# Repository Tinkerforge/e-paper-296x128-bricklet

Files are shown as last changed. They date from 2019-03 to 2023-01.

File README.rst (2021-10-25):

ePaper 128x296 Bricklet
========================

This repository contains the firmware source code and the hardware design
files. The documentation generator configs can be found at
https://github.com/Tinkerforge/generators

Repository Content
------------------

software/:
 * examples/: Examples for all supported languages
 * build/: Compiled files
 * src/: Source code of firmware
 * Makefile: Makefile to build project

hardware/:
 * Contains KiCad project files and additionally schematics as PDF

datasheets/:
 * Contains datasheets for sensors and complex ICs that are used

Hardware
--------

The hardware is designed with the open source EDA Suite KiCad
(http://www.kicad.org). Before you are able to open the files,
you have to install the Tinkerforge kicad-libraries
(https://github.com/Tinkerforge/kicad-libraries). You can either clone
them directly in hardware/ or clone them in a separate folder and
symlink them into hardware/
(ln -s kicad_path/kicad-libraries project_path/hardware). After that you
can open the .pro file in hardware/ with KiCad and from there view and
modify the schematics and the PCB layout.

Software
--------

If you want to do your own Brick/Bricklet firmware development we highly
recommend that you use our build environment setup script and read the
tutorial (https://www.tinkerforge.com/en/doc/Tutorials/Tutorial_Build_Environment/Tutorial.html).

To compile the C code we recommend you to install the newest GNU Arm Embedded
Toolchain (https://launchpad.net/gcc-arm-embedded/+download).
You also need to install bricklib2 (https://github.com/Tinkerforge/bricklib2).

You can either clone it directly in software/src/ or clone it in a
separate folder and symlink it into software/src/
(ln -s bricklib_path/bricklib2 project_path/software/src/). Finally make sure to
have CMake installed (http://www.cmake.org/cmake/resources/software.html).

After that you can build the firmware by invoking make in software/.
The firmware (.zbin) can then be found in software/build/ and uploaded
with brickv (click button "Flashing" on start screen).

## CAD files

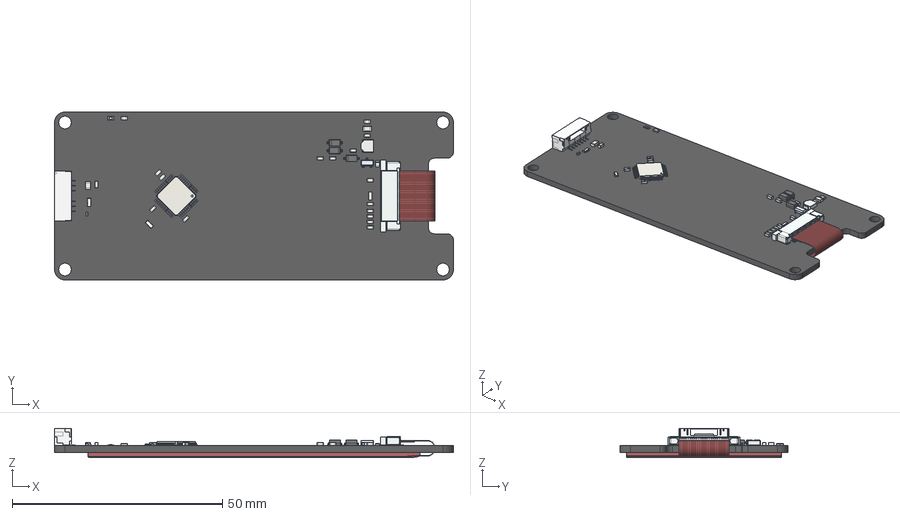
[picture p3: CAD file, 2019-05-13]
hardware/e-paper-296x128.FCStd
95.0 x 40.0 x 6.95 mm
Pcb
U2_ER-CON24HT-1_5BAE77E8
C14_C_0603_5BD03560
C1_C_0402_5BAE700F
C2_C_0603_5BAE7019
C3_C_0805_5BAE7023
C4_C_0603_5BAE702D
C5_C_0603_5BAE7037
C6_C_0603_5BAE7041
C7_C_0603_5BAE704B
C8_C_0603_5BAE7055
C9_C_0603_5BD03BE9
C10_C_0603_5BAE7069
C11_C_0603_5BAE7073
C12_C_0603_5BD0357B
C13_C_0603_5BAE7087
C15_C_0603_5BAE709B
C16_C_0603_5BAE70A5
C17_C_0603_5BAE70AF
D1_D_0603_blue_5BAE70C0
D2_SOD-123_5BAE70D4
D3_SOD-123_5BAE70E8
D4_SOD-123_5BAE70FC
L1_SPM3012_5BAE7106
P1_BrickletConn_7pin_5BAE712A
Q1_SOT23_5BAE7143
R1_R_0603_5BAE714D
R2_R_0603_5BAE7157
RP1_Cut_5BAE7167
RP2_Cut_5BAE7177
U1_lqfp48_7x7_p05_5BAE71B6
C18_C_0805_5BD07E7A
L2_R_0603_5BD075EF
RP101_Cut_5C409CBD
REF_ePaper_Display_5CD5B554

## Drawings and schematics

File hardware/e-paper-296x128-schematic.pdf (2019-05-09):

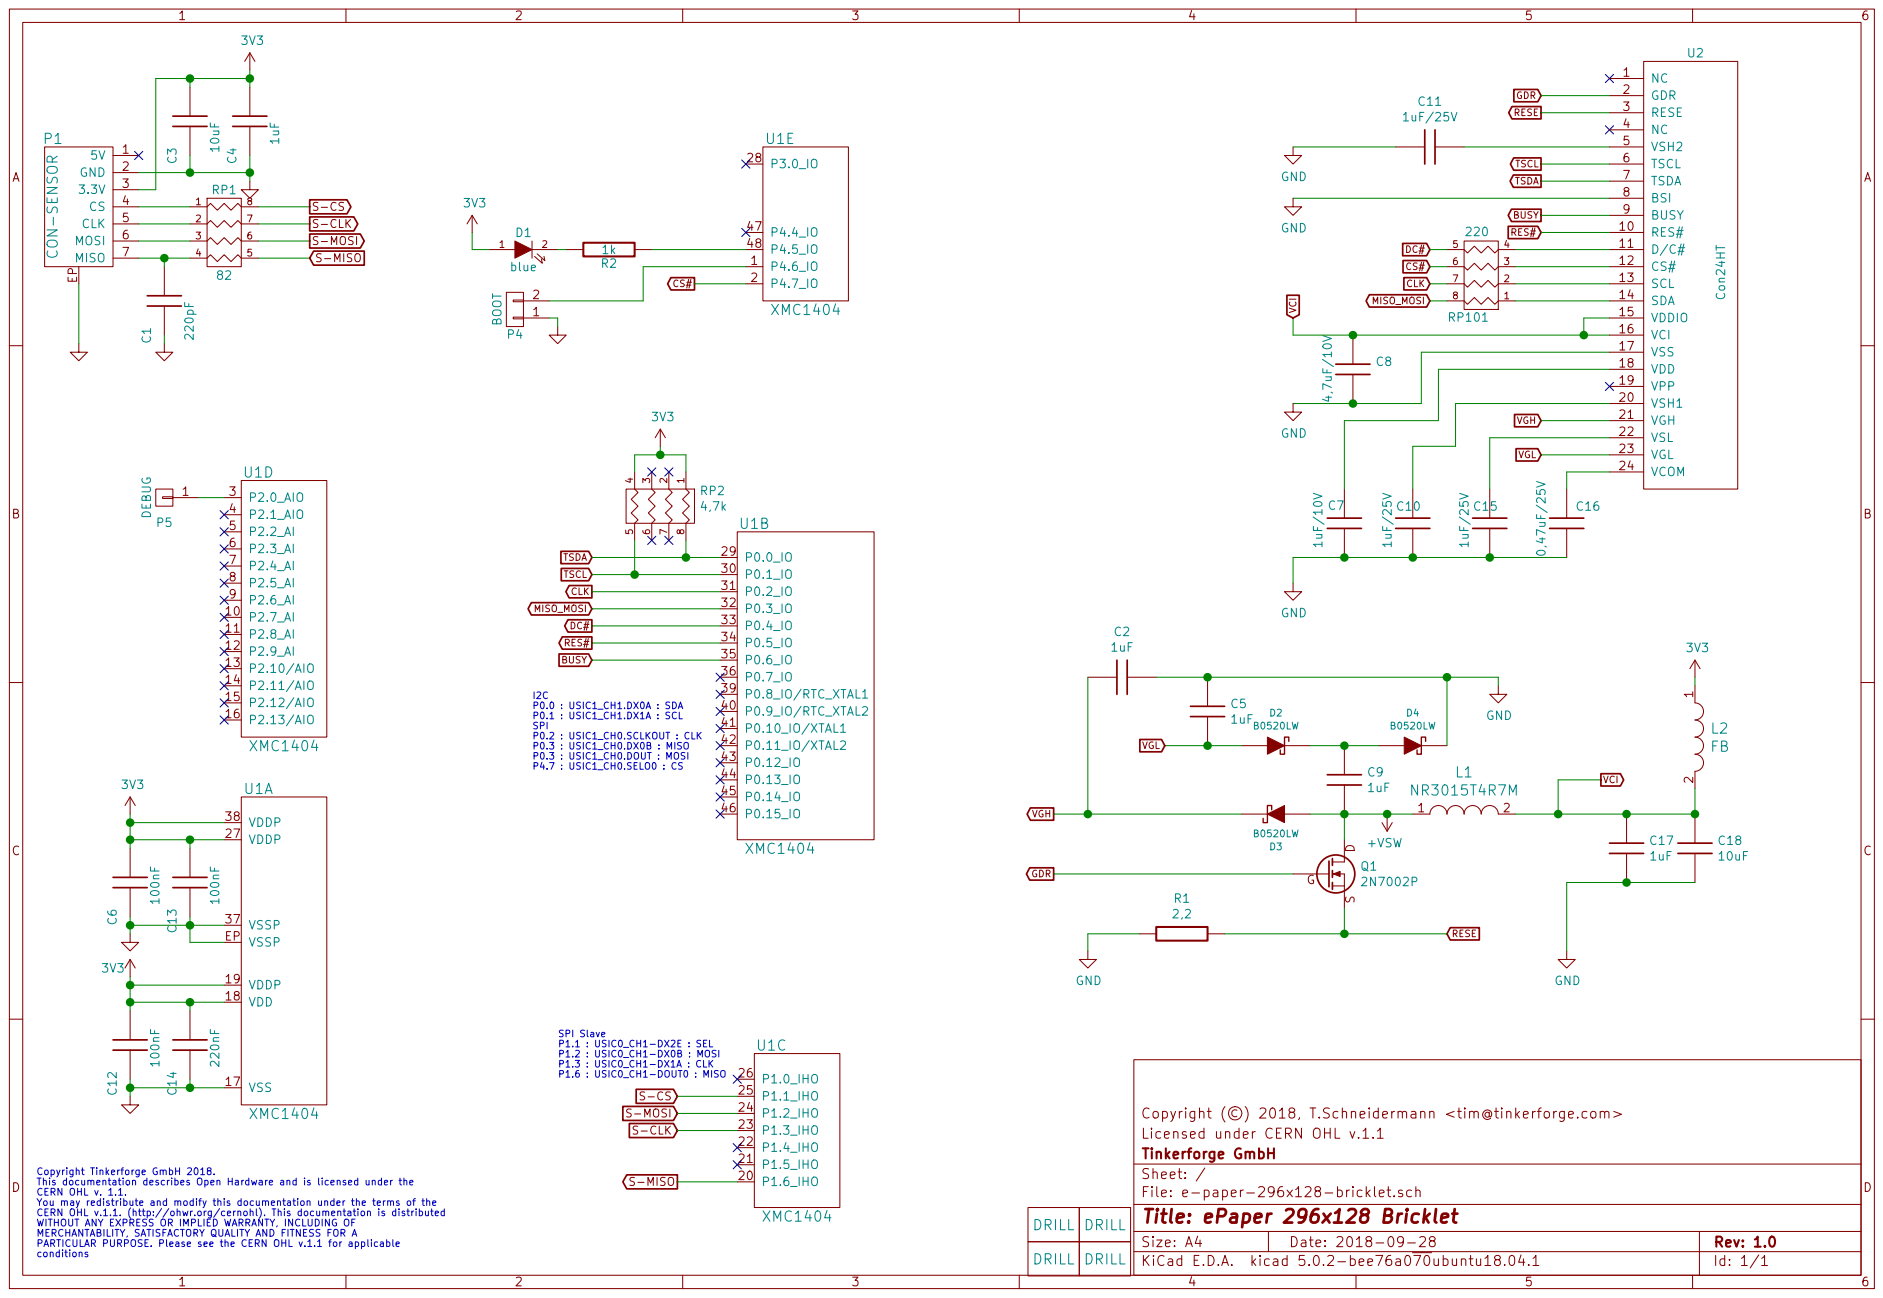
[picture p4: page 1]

SPI Slave P1.1 : USIC0_CH1-DX2E : SEL P1.2 : USIC0_CH1-DX0B : MOSI P1.3 : USIC0_CH1-DX1A : CLK

Licensed under CERN OHL v.1.1 Copyright (©) 2018, T.Schneidermann <tim@tinkerforge.com>

File: e-paper-296x128-bricklet.sch Sheet: / Tinkerforge GmbH

Copyright Tinkerforge GmbH 2018. This documentation describes Open Hardware and is licensed under the CERN OHL v. 1.1. You may redistribute and modify this documentation under the terms of the CERN OHL v.1.1. (http://ohwr.org/cernohl). This documentation is distributed WITHOUT ANY EXPRESS OR IMPLIED WARRANTY, INCLUDING OF MERCHANTABILITY, SATISFACTORY QUALITY AND FITNESS FOR A

Id: 1/1 Title: ePaper 296x128 Bricklet

PARTICULAR PURPOSE. Please see the CERN OHL v.1.1 for applicable

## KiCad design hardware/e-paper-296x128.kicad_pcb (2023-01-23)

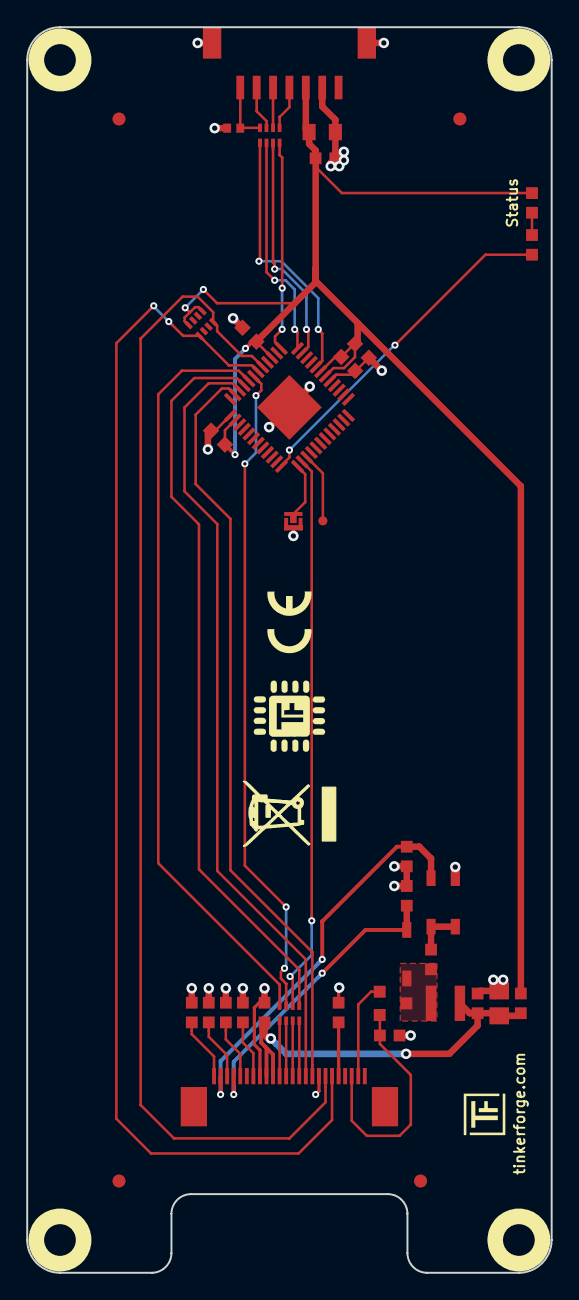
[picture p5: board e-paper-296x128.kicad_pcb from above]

Board: 2 copper layers, 40.0 x 95.0 mm, 45 parts (0 on the bottom side), 38 nets.

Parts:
C1: 220pF; C0402F
C2, C4, C5, C9, C17: 1uF; C0603F
C3: 10uF; C0805
C6, C12, C13: 100nF; C0603F
C7: 1uF/10V; C0603F
C8: 4,7uF/10V; C0603F
C10, C11, C15: 1uF/25V; C0603F
C14: 220nF; C0603F
C16: 0,47uF/25V; C0603F
C18: 10uF; C0805E
D1: blue; D0603F
D2, D3, D4: B0520LW; SOD-123
Fiducial_Mark: VAL**; Fiducial_Mark
Fiducial_Mark#2, Fiducial_Mark#3, Fiducial_Mark#4: VAL**; Fiducial_Mark
L1: NR3015T4R7M; NRH3015
L2: FB; R0603F
P1: CON-SENSOR; CON-SENSOR2
P4: BOOT; SolderJumper
P5: DEBUG; DEBUG_PAD
Q1: 2N7002P; SOT23GDS
R1: 2,2; R0603F
R2: 1k; R0603F
RP1: 82; 4X0402
RP2: 4,7k; 4X0402
RP101: 220; 4X0402
U1: XMC1404; QFN48-EP2
U2: Con24HT; ER-CON24HT-1
U4, U5, U6, U7: DRILL; DRILL_NP
VAL: CE_5mm
VAL#2: WEEE_7mm

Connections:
3V3: C3.2, C4.2, C6.2, C12.2, C13.2, C14.2, D1.1, L2.1, P1.3, RP2.1, RP2.4, U1.18, U1.19, U1.27, U1.38
+VSW: C9.2, D3.1, L1.1, Q1.D
BUSY: U1.35, U2.9
CLK: RP101.7, U1.31
CS#: RP101.6, U1.2
DC#: RP101.5, U1.33
GDR: Q1.G, U2.2
GND: C1.1, C2.1, C3.1, C4.1, C5.1, C6.1, C7.1, C8.2, C10.2, C11.2, C12.1, C13.1, C14.1, C15.2, C16.2, C17.2, C18.2, D4.2, P1.2, P1.EP, P4.1, R1.2, U1.17, U1.37, U1.EP, U2.8, U2.17
MISO_MOSI: RP101.8, U1.32
unnamed: C1.2, P1.7, RP1.4
unnamed: C7.2, U2.18
unnamed: C9.1, D2.2, D4.1
unnamed: C10.1, U2.20
unnamed: C11.1, U2.5
unnamed: C15.1, U2.22
unnamed: C16.1, U2.24
unnamed: D1.2, R2.2
unnamed: P1.4, RP1.1
unnamed: P1.5, RP1.2
unnamed: P1.6, RP1.3
unnamed: P4.2, U1.1
unnamed: P5.1, U1.3
unnamed: R2.1, U1.48
unnamed: RP101.1, U2.14
unnamed: RP101.2, U2.13
unnamed: RP101.3, U2.12
unnamed: RP101.4, U2.11
RES#: U1.34, U2.10
RESE: Q1.S, R1.1, U2.3
S-CLK: RP1.7, U1.23
S-CS: RP1.8, U1.25
S-MISO: RP1.5, U1.20
S-MOSI: RP1.6, U1.24
TSCL: RP2.5, U1.30, U2.6
TSDA: RP2.8, U1.29, U2.7
VCI: C8.1, C17.1, C18.1, L1.2, L2.2, U2.15, U2.16
VGH: C2.2, D3.2, U2.21
VGL: C5.2, D2.1, U2.23

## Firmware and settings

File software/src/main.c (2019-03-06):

/* e-paper-296x128-bricklet
 * Copyright (C) 2019 Olaf Lüke <olaf@tinkerforge.com>
 *
 * main.c: Initialization for E-Paper 296x128 Bricklet
 *
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
 * You should have received a copy of the GNU Lesser General Public
 * License along with this library; if not, write to the
 * Free Software Foundation, Inc., 59 Temple Place - Suite 330,
 * Boston, MA 02111-1307, USA.
 */

#include <stdio.h>
#include <stdbool.h>

#include "configs/config.h"

#include "bricklib2/bootloader/bootloader.h"
#include "bricklib2/hal/system_timer/system_timer.h"
#include "bricklib2/logging/logging.h"
#include "communication.h"
#include "ssd1675a.h"

int main(void) {
	logging_init();
	logd("Start E-Paper 296x128 Bricklet\n\r");

	communication_init();
	ssd1675a_init();

	while(true) {
		bootloader_tick();
		communication_tick();
		ssd1675a_tick();
	}
}

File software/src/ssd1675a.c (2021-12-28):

/* e-paper-296x128-v2-bricklet
 * Copyright (C) 2018-2021 Olaf Lüke <olaf@tinkerforge.com>
 *
 * ssd1675a.c: SSD1675A driver
 *
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
 * You should have received a copy of the GNU Lesser General Public
 * License along with this library; if not, write to the
 * Free Software Foundation, Inc., 59 Temple Place - Suite 330,
 * Boston, MA 02111-1307, USA.
 */

#include "ssd1675a.h"

#include "communication.h"

#include "configs/config_ssd1675a.h"
#include "bricklib2/os/coop_task.h"
#include "bricklib2/utility/util_definitions.h"

#include "xmc_spi.h"
#include "xmc_gpio.h"
#include "xmc_scu.h"

// Waveforms

// 00 = VSS  =   0V
// 01 = VSH1 =  15V
// 10 = VSL  = -15V
// 11 = VSH2 =   5V

// https://forums.pimoroni.com/t/my-inky-phat-clock-refresh-speed-question/6955/5

#define SSD1675_LUT_SIZE 70

#define SSD1675_LUT_BLACK_WHITE                                                                             \
/*    Phase 0     Phase 1     Phase 2     Phase 3     Phase 4     Phase 5     Phase 6                    */ \
/*    A B C D     A B C D     A B C D     A B C D     A B C D     A B C D     A B C D                    */ \
    0b00100010, 0b00010001, 0b00010000, 0b00000000, 0b00010000, 0b00000000, 0b00000000, /* lut0 (black)  */ \
    0b00010001, 0b10001000, 0b10000000, 0b10000000, 0b10000000, 0b00000000, 0b00000000, /* lut1 (white)  */ \
    0b00000000, 0b00000000, 0b00000000, 0b00000000, 0b00000000, 0b00000000, 0b00000000, /* lut2 (red)    */ \
    0b00000000, 0b00000000, 0b00000000, 0b00000000, 0b00000000, 0b00000000, 0b00000000, /* lut3 (red)    */ \
    0b00000000, 0b00000000, 0b00000000, 0b00000000, 0b00000000, 0b00000000, 0b00000000, /* lut4 (vcom)   */ \
																											\
/*  Duration       | Repeats           */                                                                   \
/*   A   B   C   D |                   */                                                                   \
     4, 24,  4, 22,  1,     /* Phase 0 */                                                                   \
    10, 10, 10, 10,  2,     /* Phase 1 */                                                                   \
     0,  0,  0,  0,  0,     /* Phase 2 */                                                                   \
     0,  0,  0,  0,  0,     /* Phase 3 */                                                                   \
     0,  0,  0,  0,  0,     /* Phase 4 */                                                                   \
     0,  0,  0,  0,  0,     /* Phase 5 */                                                                   \
     0,  0,  0,  0,  0,     /* Phase 6 */


#define SSD1675_LUT_DELTA                                                                                   \
/*    Phase 0     Phase 1     Phase 2     Phase 3     Phase 4     Phase 5     Phase 6                    */ \
/*    A B C D     A B C D     A B C D     A B C D     A B C D     A B C D     A B C D                    */ \
    0b00000000, 0b00000000, 0b00000000, 0b00000000, 0b00000000, 0b00000000, 0b00000000, /* lut0 (none)   */ \
    0b10000000, 0b00000000, 0b00000000, 0b00000000, 0b00000000, 0b00000000, 0b00000000, /* lut1 (b->w)   */ \
    0b01000000, 0b00000000, 0b00000000, 0b00000000, 0b00000000, 0b00000000, 0b00000000, /* lut2 (w->b)   */ \
    0b00000000, 0b00000000, 0b00000000, 0b00000000, 0b00000000, 0b00000000, 0b00000000, /* lut3 (none)   */ \
    0b00000000, 0b00000000, 0b00000000, 0b00000000, 0b00000000, 0b00000000, 0b00000000, /* lut4 (vcom)   */ \
																											\
/*  Duration       | Repeats           */                                                                   \
/*   A   B   C   D |                   */                                                                   \
    24,  0,  0,  0,  1,     /* Phase 0 */                                                                   \
     0,  0,  0,  0,  0,     /* Phase 1 */                                                                   \
     0,  0,  0,  0,  0,     /* Phase 2 */                                                                   \
     0,  0,  0,  0,  0,     /* Phase 3 */                                                                   \
     0,  0,  0,  0,  0,     /* Phase 4 */                                                                   \
     0,  0,  0,  0,  0,     /* Phase 5 */                                                                   \
     0,  0,  0,  0,  0,     /* Phase 6 */

#define SSD1675_LUT                                                                                         \
/*    Phase 0     Phase 1     Phase 2     Phase 3     Phase 4     Phase 5     Phase 6                    */ \
/*    A B C D     A B C D     A B C D     A B C D     A B C D     A B C D     A B C D                    */ \
    0b00100010, 0b00010001, 0b00010000, 0b00000000, 0b00010000, 0b00000000, 0b00000000, /* lut0 (black)  */ \
    0b00010001, 0b10001000, 0b10000000, 0b10000000, 0b10000000, 0b00000000, 0b00000000, /* lut1 (white)  */ \
    0b01101010, 0b10011011, 0b10011011, 0b10011011, 0b10011011, 0b00000000, 0b00000000, /* lut2 (red)    */ \
    0b01101010, 0b10011011, 0b10011011, 0b10011011, 0b10011011, 0b00000000, 0b00000000, /* lut3 (red)    */ \
    0b00000000, 0b00000000, 0b00000000, 0b00000000, 0b00000000, 0b00000000, 0b00000000, /* lut4 (vcom)   */ \
																											\
/*  Duration       | Repeats           */                                                                   \
/*   A   B   C   D |	               */                                                                   \
     4, 24,  4, 22,  1,     /* Phase 0 */                                                                   \
    10, 10, 10, 10,  2,     /* Phase 1 */                                                                   \
     0,  0,  0,  0,  0,     /* Phase 2 */                                                                   \
     0,  0,  0,  0,  0,     /* Phase 3 */                                                                   \
     4,  4,  8, 60,  7,     /* Phase 4 */                                                                   \
     0,  0,  0,  0,  0,     /* Phase 5 */                                                                   \
     0,  0,  0,  0,  0      /* Phase 6 */


#define SSD1680_LUT_SIZE 153
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

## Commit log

2018-09-28 initial push/ schematic template
    [e-paper-296x128-bricklet.sch]
2018-09-28 created schematic
    [e-paper-296x128-bricklet.sch]
2018-09-28 changed schematic
    [e-paper-296x128-bricklet.sch]
2018-09-28 added pcb layout / changed SPI Pins to display
    [e-paper-296x128-bricklet.kicad_pcb, e-paper-296x128-bricklet.sch]
2018-10-24 pcb design
    [e-paper-296x128-bricklet.kicad_pcb]
2018-10-24 change pcb an schematic design
    [e-paper-296x128-bricklet.kicad_pcb, e-paper-296x128-bricklet.sch]
2018-10-24 changed schematic and pcb design
    [e-paper-296x128-bricklet.kicad_pcb, e-paper-296x128-bricklet.sch]
2018-10-24 final prototype design
    [e-paper-296x128-bricklet.kicad_pcb]
2018-10-25 fix text size
    [e-paper-296x128-bricklet.kicad_pcb]
2019-01-07 add hint
    [e-paper-296x128-bricklet.kicad_pcb]
2019-01-17 shrink board by 5mm
    [e-paper-296x128-bricklet.kicad_pcb, e-paper-296x128-bricklet.sch]
2019-01-17 add fiducials, add spi serial resistor
    [e-paper-296x128-bricklet.kicad_pcb, e-paper-296x128-bricklet.sch]
2019-01-22 drc check
    [e-paper-296x128-bricklet.kicad_pcb]
2019-03-06 Add initial version of E-Paper API and driver
    [cmake_config_custom.txt]
2019-05-09 add schematic and sym lib table
2019-05-10 add e paper display footprint
    [e-paper-296x128-bricklet.kicad_pcb]
2019-05-13 add display 3d model
    [e-paper-296x128-bricklet.kicad_pcb]
2019-05-13 add 3d data
    [e-paper-296x128-bricklet.FCStd, e-paper-296x128-bricklet.kicad_pcb]
2019-05-15 fix file names
    [e-paper-296x128.FCStd, e-paper-296x128.kicad_pcb, e-paper-296x128.sch]
2019-05-28 Improve SPI IRQ performance
    Use local pointer to save the time for accessing the struct
2020-09-02 uc: Add example driver note.
2021-06-01 Add support for new driver chip (SSD1680)
2021-06-09 Fix fading image bug after power-down
    SSD1680 needs to power-down/power-up between writes,
    otherwise the image does not stay if power is removedSSD1680 needs to
    [ssd1675a.c]
2021-10-25 Update KiCad link
    https://www.kicad.org/blog/2021/10/Avoid-links-to-former-kicad-domain/
2021-12-22 Fix delta-mode for SSD1680 with new specific LUT
    [ssd1675a.c]
2021-12-28 Make sure delta-mode works all of the time
    There is some kind of race-condition with the power down sequenze
    that i can't completely figure out.
    However, it turns out that the power up sequenze itself is enough to
    make sure that the image doesn't fade out if power is removed.
    There is no relevant power saving with the power down of the
    SSD1680, so we just remove the power down sequenze.
    [ssd1675a.c]
2023-01-23 New standart layout. Switched to Kicad 6
    [e-paper-296x128.kicad_pcb, e-paper-296x128.kicad_sch, e-paper-296x128.sch]
